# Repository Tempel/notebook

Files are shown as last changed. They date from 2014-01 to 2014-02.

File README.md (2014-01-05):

A pocket notebook
=================

These are design files for a pocket notebook, designed to hold a pad of sticky
notes, a pen, and small scraps of paper.  It is designed to be made primarily
from leather and wood, using rivets to hold it together, and a snap to hold it
closed.

Files
-----

FreeCAD was used to create the overall geometries.  These were exported as SVG
files and hand modified in Inkscape to create the inputs to the laser cutter.

* _lengths.fcstd_: A top-down layout of the closed notebook, containing a full
  pad of sticky notes, both backing plates, and the leather exterior.
* _notebook.fcstd_: Layout of all parts for laser cutting.  Positioned in the
  model as if the notepad was lying face-down on a table, with the leather
  exterior on top, but flipped (leather exterior on bottom) in the drawing
  view.  The drawing view is exported as an SVG for editing in Inkscape.
* _all.svg_: Export of the drawing view from notebook.fcstd, containing all
  parts in final arrangements.  Imported into a new file (the G-code exporter
  didn't like the straight export), edited to have borders of the laser bed
  size (9" x 13"), ungrouped and converted circles to paths, then copied to
  make paths for each part individually.
* _leather.svg_ & _leather.ngc_: Toolpath and G-code for cutting the leather
  backing.  Converted to paths, split into layers, and exported with a feed
  rate of 350 mm/minute.
* _backing.svg_ & _backing.ngc_ and _pocket.svg_ & _pocket.ngc_: Toolpath and
  G-code for cutting the major wooden components.  Converted to paths, split
  into layers, and exported with a feed rate of 300 mm/min.
* _border.svg_ & _border.ngc_: Toolpath and G-code for cutting the notepad
  border pieces.  Also made out of wood, with the same feed rate, but four of
  these pieces must be cut to make a notebook, whereas only one of each other
  piece is needed.

License
-------

<br />This work is licensed under a <a rel="license" href="http://creativecommons.org/licenses/by-sa/4.0/">Creative Commons Attribution-ShareAlike 4.0 International License</a>.

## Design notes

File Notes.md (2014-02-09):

Prototype 1
===========

Made 2014-01-07 (and the next several days to finish assembly)

Observations
------------

* Rivet holes in wood fit the short rivet posts well, but were too tight for
  the large rivet posts and rivet caps.  Holes in leather had no problem
  fitting.
* Rivet heads flattened out and spread on the anvil side (not the hammer side).
  This made them marginally overlap the edges of the wood.
* Longer rivets have larger heads (~9 mm diameter).  This would have been a
  problem for the double-layered areas, but I found that the smaller caps
  worked reasonably well with the larger rivets.
* Snap works well, but has some between-material thickness that I hadn't
  accounted for in the lengths.fcstd file.
* Notepad sits a little looser than I'd like.  Looks like there's ~1.5 mm
  around all sides (3 mm on two sides when pushed into the corner).
* Pen fits well in holder.  Slightly larger might make it easier to return the
  pen while the book is in my pocket.  Peter doesn't care for the design, so
  the future may have a different approach.
* Pen sits low in holder.  There's plenty of material above, so I should move
  it up a bit.
* A full pad of sticky notes is 9.5 mm thick, thinner than the 10.16 on which
  I had based the design
* Leather is loose even with a full pad (i.e. too much material in the hinge
  and closing flap).  Looser on the hinge side than flap side, due to the
  unaccounted-for snap thickness.
* Book is a little larger than is comfortable for some of my pockets; it can be
  difficult to get in or out.

Changes
-------

* Increase rivet hole diameter from 3 mm to 3.5 mm.
* Increase rivet head landing by 1 mm.
* Use thinner wood; Peter has some at thinkhaus that's ~3/32" thick.
* Shrink notepad space by 2 mm.
* Reduce leather hinge length by 15 mm.
* Reduce leather closing flap length by 9 mm.
* Increase pen holder cut length by 1 mm.
* Raise pen holder position by 10 mm.

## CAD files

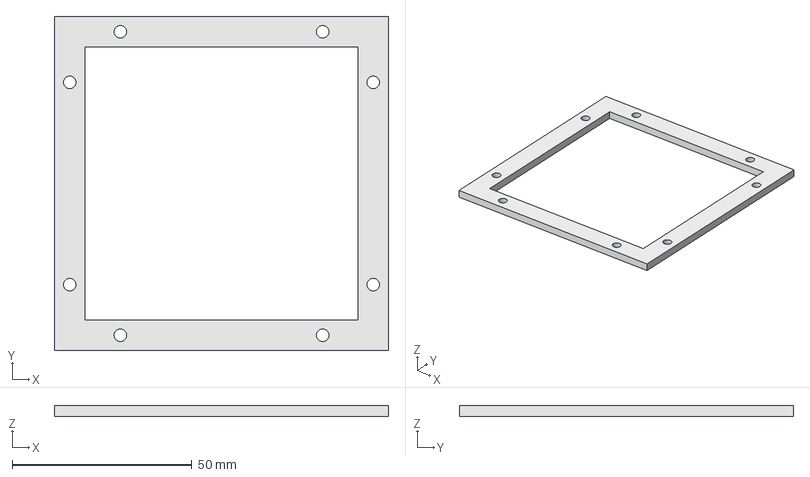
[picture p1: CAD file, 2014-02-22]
notebook.fcstd
93.0 x 93.0 x 3.00 mm

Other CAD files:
lengths.fcstd

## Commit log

2013-11-15 Started work on FreeCAD sketch layout.
    [notebook.FCStd]
2013-11-15 Actual sizes for post-its and rivet heads, but not rivet shanks.
    [notebook.FCStd]
2013-11-17 Re-did model to try to make updates not take forever.
    Also ended up doing major redesigning and restructuring.
    Note: sketch is fully constrained, but not all values are yet known, so it may
    be subject to change. Placeholder values were used just to make sure it was
    all properly constrained
    [notebook.FCStd, notebook.fcstd]
2013-11-17 Created closed layout and updated main layout accordingly.
    Used closed layout to estimate lengths needed for the hinge, snap, and pen
    holder. There are still a number of guesses made - pen diameter, hole
    diameters, wood & leather thicknesses, and how the leather will bend - but it's
    complete, pending detailed information.
    [lengths.fcstd, notebook.fcstd]
2013-11-21 Added drawing view for export.
    [notebook.fcstd]
2013-11-21 Updated with proper thicknesses of leather and hardboard.
    From Thinkhaus wiki, specifically:
    http://wiki.thinkhaus.org/index.php?title=Talk:Laser_Cutter#Feeds_.26_Speeds
    Leather is 1.2 mm thick, hardboard 1/8" (3.175 mm).
    [lengths.fcstd, notebook.fcstd]
2013-11-22 Reposition drawing to better behave with laser.
    Bottom left corner of drawing corresponds to top left corner of laser.
    [notebook.fcstd]
2013-11-22 Extracted paths and G-code for leather exterior.
    Path is still terrible, as the laser shoots around cutting edges willy-nilly.
    That is the next issue to deal with.
2013-12-17 Updated FreeCAD files with measured dimensions.
    Obtained leather, rivets, and buttons, and got wood thickness from Peter.
    With that, updated lengths.fcstd and notebook.fcstd. Also found that the
    leather is not terribly flexible, but I could imagine it loosening with time.
    [lengths.fcstd, notebook.fcstd]
2013-12-18 Leather cutting path with updated dimensions.
    Also combined all paths properly as per Peter's instructions, so this should be
    ready to cut now.
2013-12-22 Created G-code for all wood pieces.
    According to the thinkhaus wiki, 3/16" plywood floor underlay takes a feed
    speed of 300 mm/min. So these are all ready to cut!
2014-01-05 Redesigned border pieces to make it easier to use thin notepads.
    In the previous design, once the notepad becomes thinner than the wooden
    pieces, it would become impossible to pull a note up by its edge. This
    modification changes the four border pieces into corners only, leaving gaps
    between each so a finger can get at the edge. In doing so, also eliminated
    four rivets in that area, since they no longer pass through border pieces and
    would just get in the way of finger access.
    [notebook.fcstd]
2014-02-09 Added notes on the first prototype build.
    These notes will form the basis of upcoming changes.
2014-02-09 Updated FreeCAD files with new dimensions.
    Have not yet propagated through the SVG and G-code files yet; they're still
    stuck at the prototype 1 versions.
    [lengths.fcstd, notebook.fcstd]
2014-02-22 Corrected FreeCAD layout.
    Had broken the connection between the "Everything" sketch, and the "Base"
    surface to which it was attached; this caused the drawing to not update
    correctly, meaning all of my cutting layouts were effectively unchanged. Now
    the sketch has been updated correctly, so on to cutting layouts!
    [notebook.fcstd]
